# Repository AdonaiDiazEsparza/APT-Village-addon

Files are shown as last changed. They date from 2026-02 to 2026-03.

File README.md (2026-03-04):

# APT-Villa-addon
Repositorio de los recursos del Addon para el APT Village. Este es un pequeño recuerdo que se les da a las personas que participen en alguno de nuestras platicas.

<p align=center>
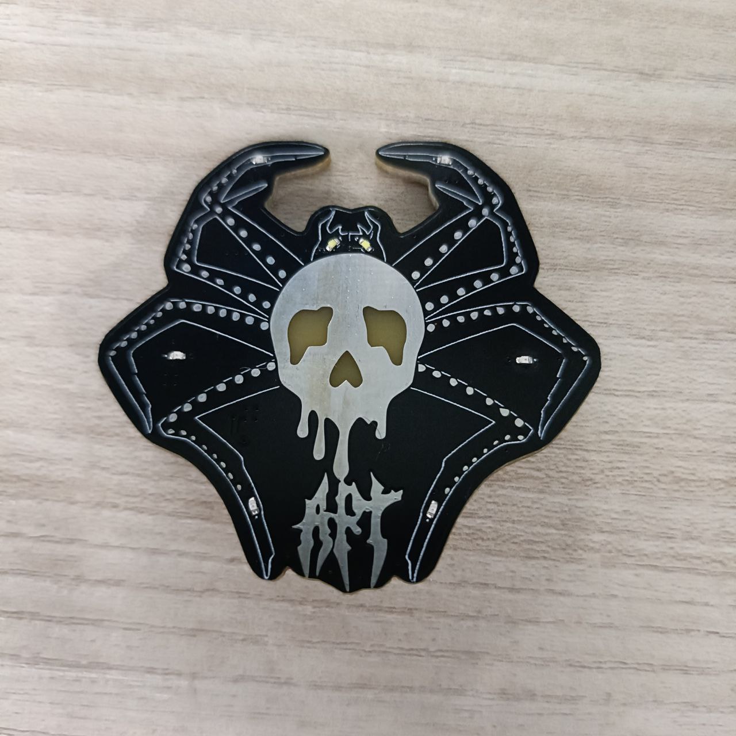
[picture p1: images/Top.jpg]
  
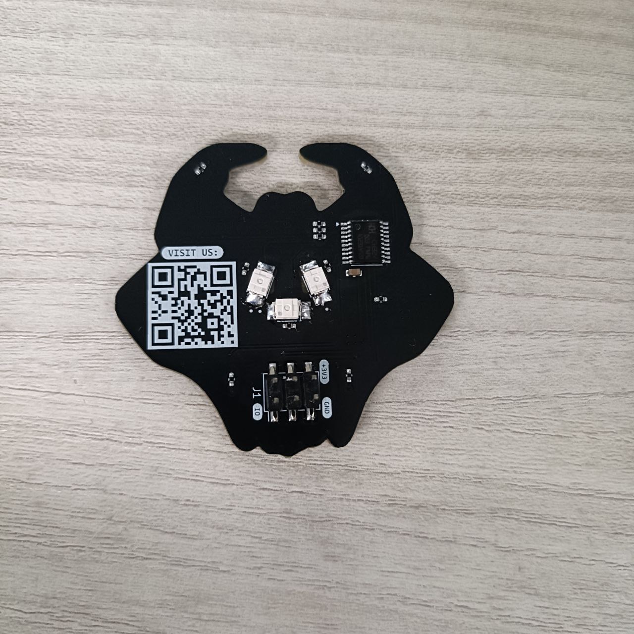
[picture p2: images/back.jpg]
  
</p>

## Hardware

- La iluminación consta de 11 Leds (6 de color rojo, 2 de color blanco y 3 traseros de color rojo).
- El chip progragramable es un CH32v003F4P6

## Firmware

### Programación

Para poder programar el chip es necesario utilizar un programador especializado, nosotros recomendamos el programador de WCH-link, pero puede funcionar otro programador que tenga soporte para chips CH32 o para arquitectura RISC-V

### Compilación

Para compilar el firmware del chip usa el comando ```make build``` para generar los archivos ```.bin``` y ```.hex```. 
Es necesario instalar los paquetes necesarios:

```shell
apt-get install build-essential libnewlib-dev gcc-riscv64-unknown-elf libusb-1.0-0-dev libudev-dev gdb-multiarch
```
Si deseas programar el chip utiliza el comando ```make flash```. 
Mas información al respecto del desarrollo de firmware con chips CH32vX, puedes ver los ejemplos en el repositorio de [CH32FUN](https://github.com/cnlohr/ch32fun).

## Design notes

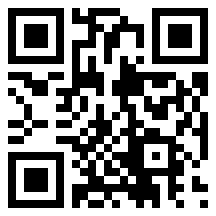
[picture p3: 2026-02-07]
hardware/resources/qr_link_corto.png

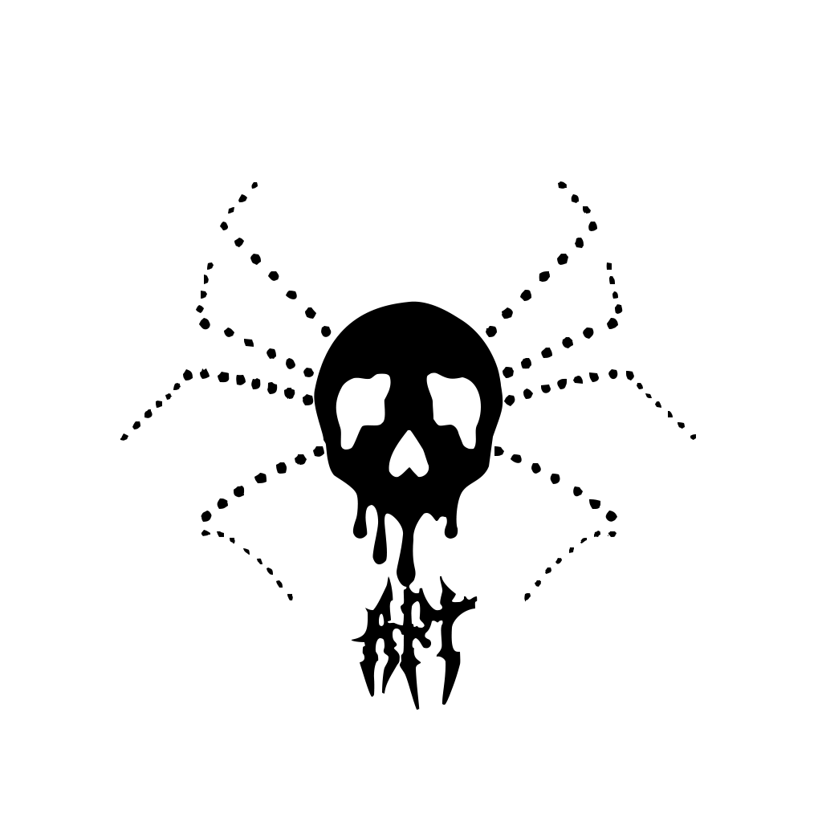
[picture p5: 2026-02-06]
hardware/resources/EDIT.png

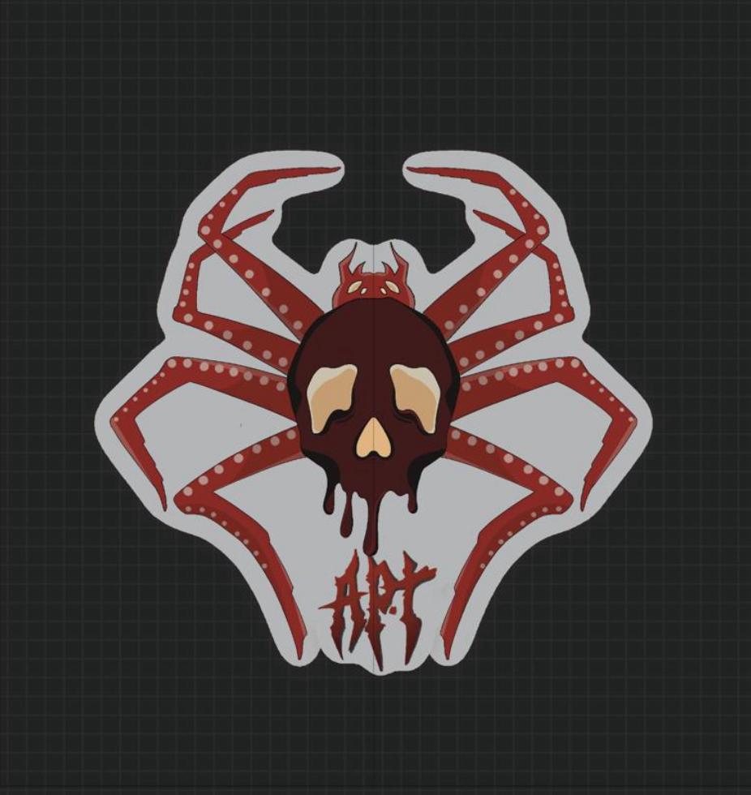
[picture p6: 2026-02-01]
hardware/resources/402671e3-078b-424f-8e60-f5cf61c12dff.jpeg

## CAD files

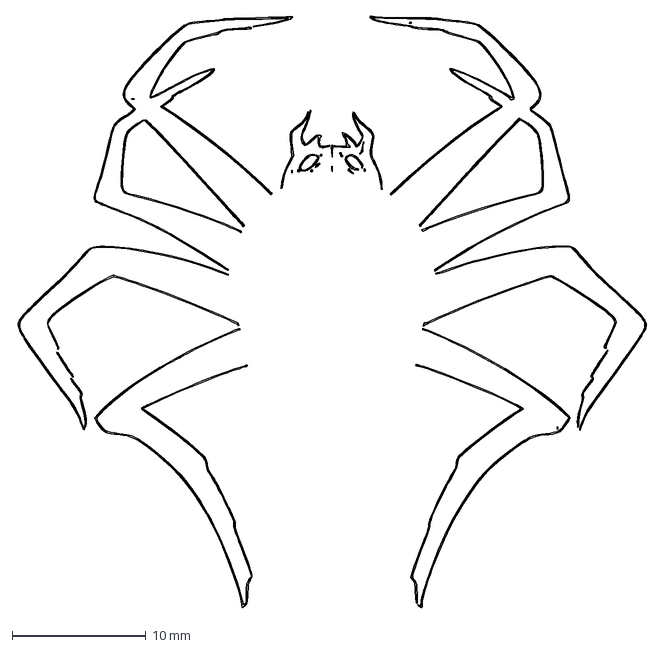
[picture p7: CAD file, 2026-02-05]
hardware/resources/patas.dxf
47.3 x 44.2 mm

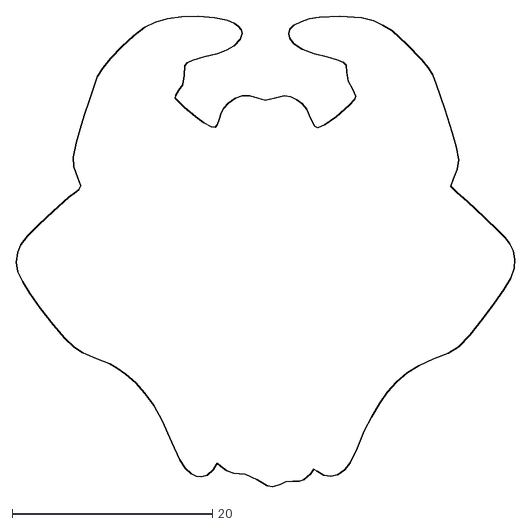
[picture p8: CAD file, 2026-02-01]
hardware/resources/contorno.dxf
49.7 x 46.9

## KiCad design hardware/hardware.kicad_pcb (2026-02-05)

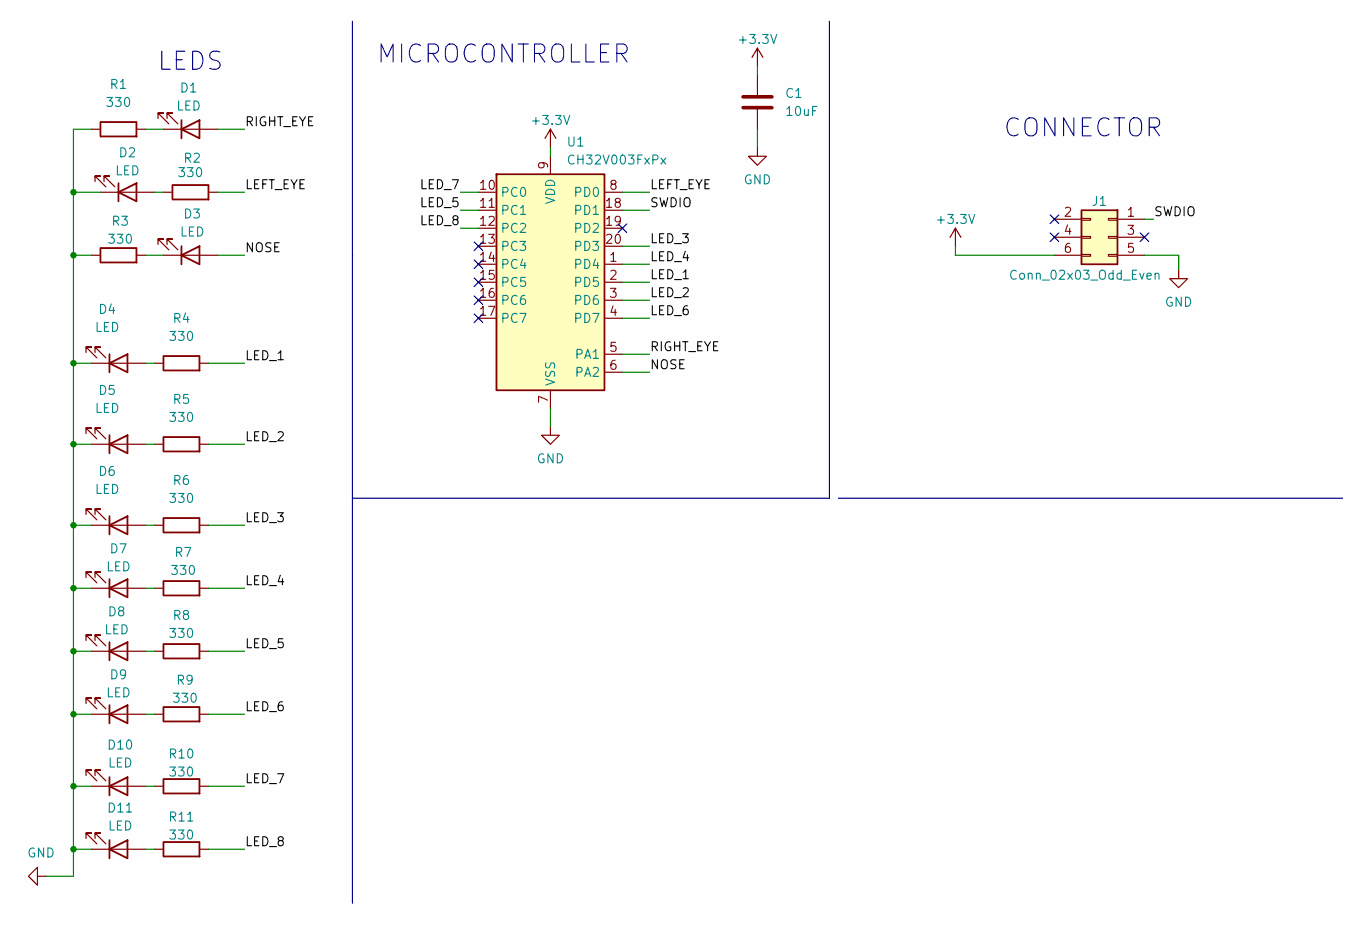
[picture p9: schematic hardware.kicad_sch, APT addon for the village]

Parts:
C1: 10uF; C_0603_1608Metric
D1, D2, D3: LED; LYT77K-K2M1
D4, D5, D6, D7, D8, D9, D10, D11: LED; LED_0402_1005Metric
J1: Conn_02x03_Odd_Even; PinHeader_2x03_P2.54mm_Vertical_SMD; LCSC# C3294461
R1, R2, R3, R4, R5, R6, R7, R8, R9, R10, R11: 330; R_0402_1005Metric_Pad0.72x0.64mm_HandSolder
U1: CH32V003FxPx; TSSOP-20_4.4x6.5mm_P0.65mm; LCSC# C5187096

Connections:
+3.3V: C1.1, J1.6, U1.9 (VDD)
/LED_1: R4.2, U1.2 (PD5)
/LED_2: R5.2, U1.3 (PD6)
/LED_3: R6.2, U1.20 (PD3)
/LED_4: R7.2, U1.1 (PD4)
/LED_5: R8.2, U1.11 (PC1)
/LED_6: R9.2, U1.4 (PD7)
/LED_7: R10.2, U1.10 (PC0)
/LED_8: R11.2, U1.12 (PC2)
/LEFT_EYE: R2.2, U1.8 (PD0)
/NOSE: D3.2 (A), U1.6 (PA2)
/RIGHT_EYE: D1.2 (A), U1.5 (PA1)
/SWDIO: J1.1, U1.18 (PD1)
GND: C1.2, D2.1 (K), D4.1 (K), D5.1 (K), D6.1 (K), D7.1 (K), D8.1 (K), D9.1 (K), D10.1 (K), D11.1 (K), J1.5, R1.1, R3.1, U1.7 (VSS)
unnamed: D1.1 (K), R1.2
unnamed: D2.2 (A), R2.1
unnamed: D3.1 (K), R3.2
unnamed: D4.2 (A), R4.1
unnamed: D5.2 (A), R5.1
unnamed: D6.2 (A), R6.1
unnamed: D7.2 (A), R7.1
unnamed: D8.2 (A), R8.1
unnamed: D9.2 (A), R9.1
unnamed: D10.2 (A), R10.1
unnamed: D11.2 (A), R11.1

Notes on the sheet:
LEDS
CONNECTOR
MICROCONTROLLER

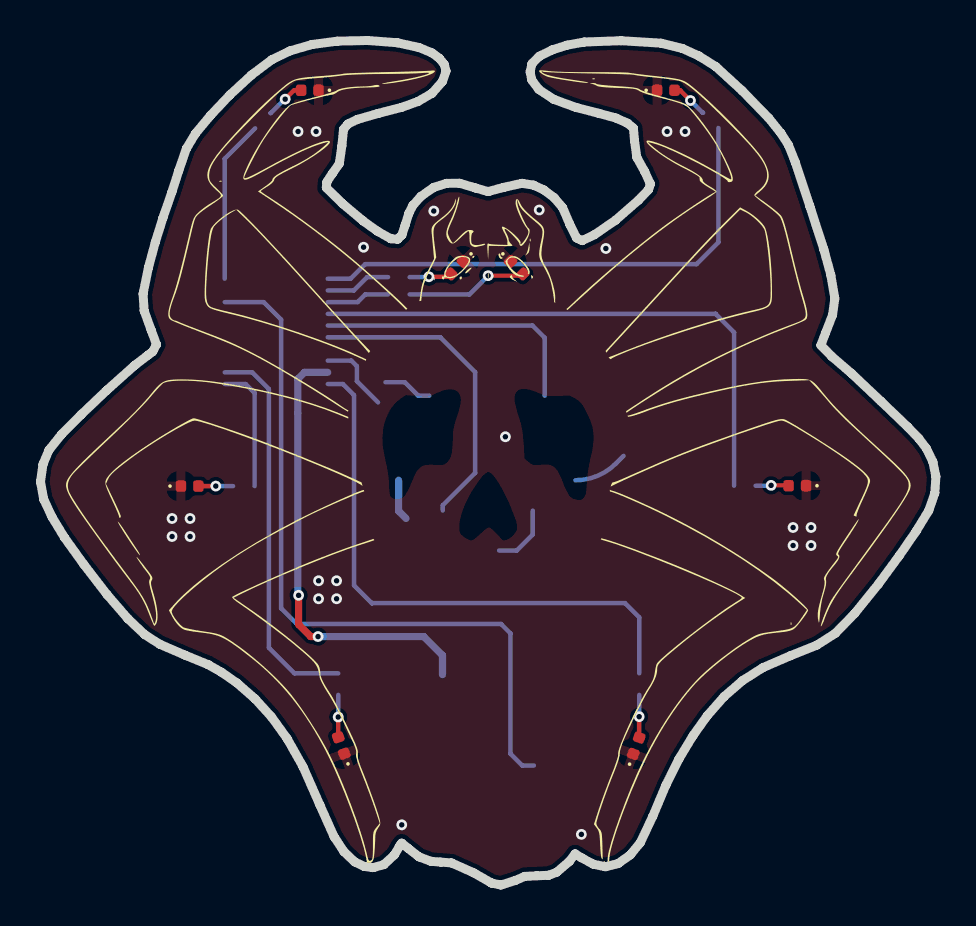
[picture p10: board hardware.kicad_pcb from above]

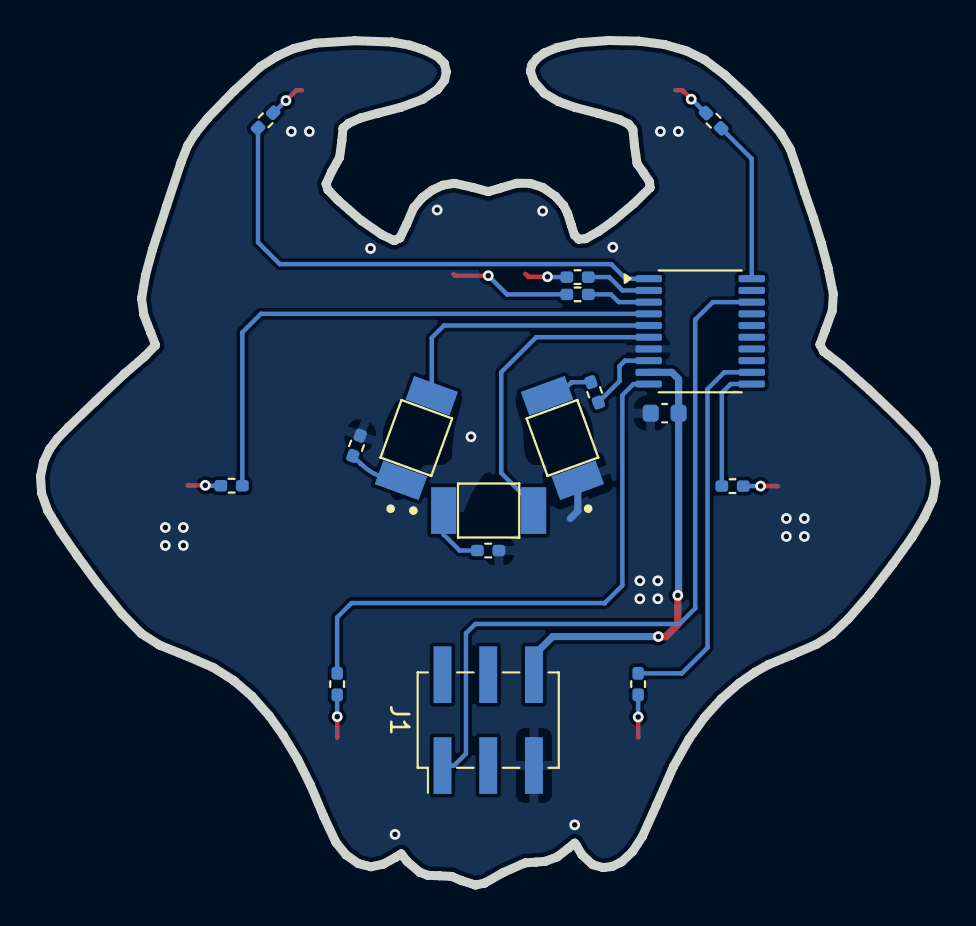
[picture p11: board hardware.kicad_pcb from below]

Board: 2 copper layers, 49.7 x 46.9 mm, 28 parts (17 on the bottom side), 25 nets.

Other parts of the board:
Ref**: Val**; dots
Ref**#2: Val**; front_eyes
Ref**#3: Val**; drawing

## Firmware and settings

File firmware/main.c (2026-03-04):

#include "main.h"

/**
 * Define the structs for the leds
 */
led_t led_1 = {
    .led = LED_1,
    .pwm = 0
};

led_t led_2 = {
    .led = LED_2,
    .pwm = 0
};

led_t led_3 = {
    .led = LED_3,
    .pwm = 0
};

led_t led_4 = {
    .led = LED_4,
    .pwm = 0
};

led_t led_5 = {
    .led = LED_5,
    .pwm = 0
};

led_t led_6 = {
    .led = LED_6,
    .pwm = 0
}; 

led_t led_7 = {
    .led = LED_7,
    .pwm = 0
}; 

led_t led_8 = {
    .led = LED_8,
    .pwm = 0
}; 


led_t led_nose = {
    .led = NOSE,
    .pwm = 0
}; 


led_t led_right = {
    .led = RIGHT_EYE,
    .pwm = 0
}; 

led_t led_left = {
    .led = LEFT_EYE,
    .pwm = 0
}; 

// ====================================== HANDLE FOR INTERRUPTS ============

// Defines for the systick
#define millis() (systick_millis)
#define micros() (SysTick->CNT / DELAY_US_TIME)

volatile uint32_t systick_millis;

// Counter
volatile uint16_t counter = 0;

// Timer Interrupt
void TIM1_UP_IRQHandler(void) __attribute__((interrupt));
void TIM1_UP_IRQHandler(void)
{
    if (TIM1->INTFR & TIM_FLAG_Update)
    {
        TIM1->INTFR &= ~TIM_FLAG_Update;

        counter++;

        if (counter >= 1000)
            counter = 0;

        funDigitalWrite(led_1.led, counter<led_1.pwm);
        funDigitalWrite(led_2.led, counter<led_1.pwm);
        funDigitalWrite(led_3.led, counter<led_3.pwm);
        funDigitalWrite(led_4.led, counter<led_4.pwm);
        funDigitalWrite(led_5.led, counter<led_5.pwm);
        funDigitalWrite(led_6.led, counter<led_6.pwm);
        funDigitalWrite(led_7.led, counter<led_7.pwm);
        funDigitalWrite(led_8.led, counter<led_8.pwm);
        funDigitalWrite(led_left.led, counter<led_nose.pwm);
        funDigitalWrite(led_right.led, counter<led_nose.pwm);
        funDigitalWrite(led_nose.led, counter<led_nose.pwm);
    }
}

// Systick interrupt handler
void SysTick_Handler(void) __attribute__((interrupt));
void SysTick_Handler(void)
{
	SysTick->CMP += DELAY_MS_TIME;
	SysTick->SR = 0x00000000;
	systick_millis++;
}

/**
 * Delay functions
 */

void delay_ms(uint32_t time)
{
    uint32_t last_time = millis();

    while(millis() - last_time < time);
}

/**
 * Init the Timer
 */
void timer_init(void)
{
    RCC->APB2PCENR |= RCC_APB2Periph_TIM1;

    TIM1->CTLR1 = 0;
    TIM1->CTLR2 = 0;
    TIM1->RPTCR = 0;

    // 48MHz / 48 = 1MHz (1us)
    TIM1->PSC = 47;

    // 1MHz / 1000 = 1kHz (1ms)
    TIM1->ATRLR = 10 - 1;

    TIM1->SWEVGR = TIM_PSCReloadMode_Update;

    TIM1->INTFR &= ~TIM_FLAG_Update;
    TIM1->DMAINTENR |= TIM_IT_Update;

    NVIC_EnableIRQ(TIM1_UP_IRQn);

    TIM1->CTLR1 |= TIM_CEN;
}

/**
 * Init the Systick
 */
void systick_init(void)
{
	SysTick->CTLR = 0x0000;
	SysTick->CMP = DELAY_MS_TIME - 1;
	SysTick->CNT = 0x00000000;
	systick_millis = 0x00000000;
	
	SysTick->CTLR |= SYSTICK_CTLR_STE   |  // Enable Counter
	                 SYSTICK_CTLR_STIE  |  // Enable Interrupts
	                 SYSTICK_CTLR_STCLK ;  // Set Clock Source to HCLK/1
	
	NVIC_EnableIRQ(SysTick_IRQn);
}

/**
 * Init all the leds
 */
void InitLeds(void){
    INIT_LED(LED_1);
    INIT_LED(LED_2);
    INIT_LED(LED_3);
    INIT_LED(LED_4);
    INIT_LED(LED_5);
    INIT_LED(LED_6);
    INIT_LED(LED_7);
    INIT_LED(LED_8);

    INIT_LED(RIGHT_EYE);
    INIT_LED(LEFT_EYE);
    INIT_LED(NOSE);
}

/**
 * Function to init all
 */
void InitAddon()
{
	SystemInit(); // Init system

    funGpioInitAll(); // Init all gpio

	timer_init(); // Start timer

    systick_init(); // Init the systick system

    InitLeds(); // Iniciar todos los leds
}

/**
 * All leds turn off
 */
void all_off(){
    led_1.pwm = 0;
    led_2.pwm = 0;
    led_3.pwm = 0;
    led_4.pwm = 0;
    led_5.pwm = 0;
    led_6.pwm = 0;
    led_7.pwm = 0;
    led_8.pwm = 0;
    led_nose.pwm = 0;
    led_left.pwm = 0;
    led_right.pwm = 0;
}

/**
 *  Squence
 */
void sequence()
{
    led_t* leds_right[] = {&led_4, &led_6, &led_5};
    led_t* leds_left[] = {&led_3, &led_7, &led_8};

    uint8_t pivot = 0;
    int8_t direction = 1, pivot_nose_eyes = 0;

    uint32_t last_time_eyes = millis() ,last_time_feet = millis(), last_time_nose = millis(), last_time_light_feet = millis(); 

    leds_left[0]->pwm = 1000;
    leds_right[0]->pwm = 1000;

    uint16_t value_foot = 0;

    all_off();

    // ======================== At this point the leds around need to start growing thier values ======================

    last_time_light_feet = millis();

    while(value_foot < 200){
        uint32_t current_time = millis();

        if(current_time - last_time_light_feet > 100){
            value_foot += 5;
            last_time_light_feet = current_time;
        }

        if(current_time - last_time_feet > 150 ){

            for(uint8_t i = 0; i<3; i++){
                leds_left[i]->pwm = 0;
                leds_right[i]->pwm = 0;
            }

            pivot+=direction;

            leds_left[pivot]->pwm = value_foot;
            leds_right[pivot]->pwm = value_foot;

            if(pivot == 0) direction = 1;
            if(pivot == 2) direction = -1;

            last_time_feet = current_time;
        }
    }

    // ======================== Start growing the values of the eyes on the spider ======================

    last_time_eyes = millis();

    while(led_1.pwm < 500)
    {
        uint32_t current_time = millis();

        if(current_time - last_time_eyes > 50 ){
            led_1.pwm += 10;
            last_time_eyes = current_time;
        }

        if(current_time - last_time_feet > 150 ){

            for(uint8_t i = 0; i<3; i++){
                leds_left[i]->pwm = 0;
                leds_right[i]->pwm = 0;
            }

            pivot+=direction;

            leds_left[pivot]->pwm = value_foot;
            leds_right[pivot]->pwm = value_foot;

            if(pivot == 0) direction = 1;
            if(pivot == 2) direction = -1;

            last_time_feet = current_time;
        }
    }

    // ======================== Start iluminating the eyes and nose for the skull ======================
    
    last_time_nose = millis();

    while(led_nose.pwm < 1000)
    {
        uint32_t current_time = millis();

        if(current_time - last_time_nose > 25 ){
            led_nose.pwm += 10;
            last_time_nose = current_time;
        }

        if(current_time - last_time_feet > 150 ){

            for(uint8_t i = 0; i<3; i++){
                leds_left[i]->pwm = 0;
                leds_right[i]->pwm = 0;
            }

            pivot+=direction;

            leds_left[pivot]->pwm = value_foot;
            leds_right[pivot]->pwm = value_foot;

            if(pivot == 0) direction = 1;
            if(pivot == 2) direction = -1;

            last_time_feet = current_time;
        }
    }

    // ======================== A time fade in out ======================

    last_time_eyes = millis();

    while(true){
        if(led_nose.pwm == 1000) pivot_nose_eyes = -20;
        if(led_nose.pwm == 20) pivot_nose_eyes = 20;

        uint32_t current_time = millis();

        if(current_time - last_time_nose > 10){
            led_nose.pwm += pivot_nose_eyes;
            last_time_nose = current_time;
        }

        if(current_time - last_time_feet > 150 ){

            for(uint8_t i = 0; i<3; i++){
                leds_left[i]->pwm = 0;
                leds_right[i]->pwm = 0;
            }

            pivot+=direction;

            leds_left[pivot]->pwm = value_foot;
            leds_right[pivot]->pwm = value_foot;

            if(pivot == 0) direction = 1;
            if(pivot == 2) direction = -1;

            last_time_feet = current_time;
        }

        if(current_time - last_time_eyes > 20000){
            break;
        }
    }

    // ======================== Start going down the eyes of the spider ======================

    last_time_light_feet = millis();

    while(value_foot != 0){
        uint32_t current_time = millis();

        if(led_nose.pwm == 1000) pivot_nose_eyes = -20;
        if(led_nose.pwm == 20) pivot_nose_eyes = 20;

        if(current_time - last_time_light_feet > 100){
            value_foot -= 5;
            last_time_light_feet = current_time;
        }

        if(current_time - last_time_feet > 150 ){

            for(uint8_t i = 0; i<3; i++){
                leds_left[i]->pwm = 0;
                leds_right[i]->pwm = 0;
            }

            pivot+=direction;

            leds_left[pivot]->pwm = value_foot;
            leds_right[pivot]->pwm = value_foot;

            if(pivot == 0) direction = 1;
            if(pivot == 2) direction = -1;

            last_time_feet = current_time;
        }
    
        if(current_time - last_time_nose > 10){
            led_nose.pwm += pivot_nose_eyes;
            last_time_nose = current_time;
        }
    }

    leds_left[pivot]->pwm = value_foot;
    leds_right[pivot]->pwm = value_foot;

    // ======================== start turning off the lights ======================

    last_time_eyes = millis();

    while (led_1.pwm != 0)
    {
        uint32_t current_time = millis();

        if(led_nose.pwm == 1000) pivot_nose_eyes = -20;
        if(led_nose.pwm == 20) pivot_nose_eyes = 20;
        
        if(current_time - last_time_eyes > 50){
            led_1.pwm -= 25;
            last_time_eyes = current_time;
        }

        if(current_time - last_time_nose > 10){
            led_nose.pwm += pivot_nose_eyes;
            last_time_nose = current_time;
        }
    }
    
    // ======================== play a little with the eyes and the nose ======================

    last_time_eyes = millis();

    while(true){
        if(led_nose.pwm == 1000) pivot_nose_eyes = -20;
        if(led_nose.pwm == 20) pivot_nose_eyes = 20;

        uint32_t current_time = millis();

        if(current_time - last_time_nose > 10){
            led_nose.pwm += pivot_nose_eyes;
            last_time_nose = current_time;
        }

        if(current_time - last_time_eyes > 5000){
            break;
        }
    }

    while(led_nose.pwm < 1000){
        if(led_nose.pwm == 20) pivot_nose_eyes = 20;

        uint32_t current_time = millis();

        if(current_time - last_time_nose > 10){
            led_nose.pwm += pivot_nose_eyes;
            last_time_nose = current_time;
        }
    }

    // ========================== fade down =================================================

    while(led_nose.pwm != 0){
        uint32_t current_time = millis();

        if(current_time - last_time_nose > 100){
            led_nose.pwm -= 20;
            last_time_nose = current_time;
        }
    }
    
    delay_ms(1000);
}

/**
 * Main Function
 */
int main()
{

	InitAddon(); // Init All functions

    delay_ms(100);

	while(1)
	{
        sequence();
	}
}

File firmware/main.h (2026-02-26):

#include "ch32fun.h"
#include <stdbool.h>
#include <stdio.h>

#define RIGHT_EYE   PA1
#define LEFT_EYE    PD0
#define NOSE        PA2

#define LED_1       PD4
#define LED_2       PD5
#define LED_3       PD2
#define LED_4       PD3
#define LED_5       PC0
#define LED_6       PD6
#define LED_7       PC1
#define LED_8       PC2

// Init leds
#define INIT_LED(led) funPinMode(led, GPIO_Speed_10MHz | GPIO_CNF_OUT_PP);

// Struct to control the pwm led
typedef struct {
    uint8_t led;
    volatile uint16_t pwm;
} led_t;

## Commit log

2026-01-29 feat(hw): add hardware project
    [hardware.kicad_pcb, hardware.kicad_sch]
2026-02-01 feat: add resources
    [contorno.dxf, hardware.kicad_pcb]
2026-02-01 feat: add zones with no cooper
    [hardware.kicad_pcb]
2026-02-02 feat: add footprints
    [hardware.kicad_pcb]
2026-02-04 feat: update pcb
    [hardware.kicad_pcb]
2026-02-04 feat: add routes
    [hardware.kicad_pcb, hardware.kicad_sch]
2026-02-05 feat: add vias
    [hardware.kicad_pcb, hardware.kicad_sch]
2026-02-05 feat: add more designs
    [hardware.kicad_pcb, patas.dxf]
2026-02-06 refactor(hw): remove routes
    [hardware.kicad_sch]
2026-02-07 feat(hw): add qr and components number
    [hardware.kicad_sch]
2026-02-23 test: timer on firmware
2026-02-25 feat: add struct for the pwm
2026-02-26 feat: add pwm examples
2026-10-08 feat: change routes and components place
    [hardware.kicad_pcb, hardware.kicad_sch]
